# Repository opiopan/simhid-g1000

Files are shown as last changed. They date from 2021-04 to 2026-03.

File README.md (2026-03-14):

SimHID G1000
===
<p align="center">
description
</p>

SimHID G1000 is a input device that imitates Garmin G1000 glass cockpit system for controlling flight simulators.<br>
This device is designed to utilize a iPad as a display.
iPad, iPad Air or iPad Pro with a display from 10.2 inches to 11 inches can be applied to this device.<br>

SimHID G1000 not only has 41 push buttons and 14 axes rotary encoders like the actual Garmin G1000,
but also has a total 6 input switches on both side of left and right sides.
These additional switches allow you to switch one device between PFD and MFD for both purposes.<br>

SimHID G1000 behaves as a USB virtual serial device, and communicate with the host using proprietary protocol named SimHID protocol.
In order to recognize this protocol and to control switching between PFD and MFD, I made a Windows application called [fsmapper](https://opiopan.github.io/fsmapper).

## How to build
<p align="center">
description
</p>

The above image shows all parts that make up SimHID G1000.<br>
Most parts are 3D printed by FDM, but some parts are cut out and engraved from a 2mm thick acrylic plate using a laser cutter.
The model data for 3D printer and laser cutter are published at [Thingiverse](https://www.thingiverse.com/thing:4966493). Regarding these models, please refer [here](https://www.thingiverse.com/thing:4966493).

In this Github repository, PCB design and firmware source codes are hosted.<br>
Regarding PCB design related information include manufacturing, please refer README at [here](pcb/).<br>

Once all parts of SimHID G1000 are prepared, please assemble those according to [this procedure](docs/how-to-assemble.md).

**Note**: |
:----|
SimHID G1000 is entirely designed using [Fusion 360](https://www.autodesk.com/products/fusion-360/overview), including both mechanical and electrical components. If you want to modify the parts design, download [this Fusion 360 design file](https://raw.githubusercontent.com/wiki/opiopan/simhid-g1000/data/SimHID-G1000.f3d) and upload it to your Fusion 360 workspace.<br>Note that this file includes the 3D model of the PCB but does not contain the original netlist or artwork. The PCB design files are published separately [here](pcb), so upload them to Fusion 360 as well.

## Compatible iPad
board image

SimHID G1000 uses an iPad as display. 
I assume that an iPad behave as second display of Windows PC by using an application such as [Duet Display](https://duetdisplay.com),
and show PFD or MFD images rendered by a flight simulator.<br>
An iPad can be easily inserted from the top of the SimHID G1000 along the guide like as the right image.<br>
I've confirmed to fit with SimHID G1000 only in case of iPad Air gen 3, 
but I believe that all iPad families with display from 10.2 inches to 11 inches can be fit.

The iPad list compatible with SimHID G1000 is below (as of Mar. 2026).

|Class | Model
|:---:|---|
|iPad Pro | iPad Pro 10.5″<br>iPad Pro 11″ Gen 1<br>iPad Pro 11″ Gen 2<br>iPad Pro 11″ Gen 3<br>iPad Pro 11″ M4<br>iPad Pro 11″ M5
|iPad Air | iPad Air Gen 3<br>iPad Air Gen 4<br>iPad Air Gen 5<br>iPad Air 11″ M2<br>iPad Air 11″ M3<br>iPad Air 11″ M4
|iPad | iPad Gen 7<br>iPad Gen 8<br>iPad Gen 9<br>iPad Gen 10<br>iPad A16

## Compiling firmware
**Note**: |
:----|
The pre-built firmware can be downloaded from [here](https://github.com/opiopan/simhid-g1000/releases/latest/). If you haven’t modified the firmware code, using this version will be easier.

1. **Requirements**<br>
    Ensure that the [Arm GNU Toolchain](https://developer.arm.com/downloads/-/arm-gnu-toolchain-downloads) is installed and its bin folder is added to the `PATH` environment variable.
    Note that you need to install the toolchain for **AArch32 bare-metal** (`arm-none-eabi` variant).

    The Makefile for this firmware code is written with the assumption that it will be built in a Unix-like environment.
    If you are building on Windows, I strongly recommend using the Linux version of the Arm GNU Toolchain on WSL2.

2. **Downloading Source Codes**<br>
    ```shell
    $ git clone https://github.com/opiopan/simhid-g1000.git
    ```

3. **Compiling**
    ```shell
    $ cd simhid-g1000/firmware
    $ make all

## Programming Firmware
Once compiling as the above steps is done, following firmware binary files are made.
- ```firmware/build/simhid-g1000.elf``` : ELF format binary
- ```firmware/build/simhid-g1000.bin``` : raw binary

You can choose two way to program firmware to SimHID G1000.<br>
One is programming firmware via SWD by using debugger.  SimHID G1000 PCB exports a SWD I/F and you can access that from backside of this device.<br>
The other one is programming it via USB port in DFU mode. You can switch SimHID G1000 in DFU mode by inserting that to USB port with the button at right side pressed.

### Programming via Debugger
1. **Preparing Debugger**<br>
    Make sure that a debugger is connected with swd port (J6) and debugger controlling software which behave as GDB server such as OpenOCD is running.<br>
    Note that the J6 port does not have a power terminal, so you need to connect a USB port to supply power.

2. **Programming**<br>
    You can program a firmware by making ```flash``` target with ```DEBUGSERVER``` parameter.
    If debugger controlling software is running same PC, specify ```localhost``` for ```DEBUGSERVER``` parameter.

    ```shell
    $ make DEBUGSERVER=localhost flash
    ```
### Programming via USB
board image

1. **Install required software**<br>
    Make sure that software with programming function via DFU is installed.
    Following softwares are populor to use for this purpose.
    - [STM32CubeMXProgrammer](https://www.st.com/ja/development-tools/stm32cubeprog.html)
    - [dfu-util](http://dfu-util.sourceforge.net)

2. **Switching SimHID G1000 in DFU mode**<br>
    Hold down the button on the right side of SimHID G1000 and connect that with USB port on PC.

3. **Programming**<br>
    In case using dfu-util, you can program just by making ```dfuflash``` target.

    ```shell
    $ make dfuflash
    ```

    Othrewise, follow the instructions for the software you are using.

4. **Exsiting from DFU mode**<br>
    Pull out SimHID G1000 from USB port on PC, then re-connect that to USB port.

## SimHID protocol
SimHID G1000 communicate with PC using a proprietary protocol named SimHID protocol via USB virtual serial port.<br>
Initially, I was considering that SimHID G1000 behaves as USB HID device which can be handled by Windows standard USB gaming controller device driver.
However in the end, I decided to implement a proprietary protocol because of two issues.<br>

One issue is distinguishability of each operable elements.<br>
SimHID G1000 consists of 47 binary switches (push buttons) and 14 axes rotary encoders. when each rotary encoders is expressed 2 push buttons, such as for clockwise and for counter clockwise, SimHID G1000 is recognized as a device that consists of 75 buttons. In case handling this device by the standard USB HID gaming controller device driver, all buttons are distinguished only by their serial number. For example, the push button on top of the rotary encoder for setting the navigation frequency is #12, the switch representing the left of joystick for map panning is #62.<br>
This situation is very complicated for me when I setting up the mappings between SimHID G1000 operation and aircraft control. 
I wanted to assign each operable elements a descriptive name.

The other one issue was actually based on my misunderstanding regarding rotary encoder performance.<br>
I estimated that multiple clicks by rotary encoder's rotation can occur during the communication interval with host. It means that click event may be dropped if each click event is expressed as a simple push button.<br>
So, I tried to express each axes of rotary encoder as a analog axis of USB gaming controller device.
However, I soon realized that this plan doesn't work because Windows standard USB gaming controller device driver limits the number of analog axes to a maximum of 8
even though there is no limit in the USB HID specification.<br>
In practice, only one click event occurs during the communication interval with host in normal usage, and there is no problem even if each rotation click event is expressed as push button down and up event.<br>

In summary, I decided to design a new proprietary protocol and implement that due to the former issue.

SimHID protocol is designed to be both human readable and machine readable.
You can observe communication data between a SimHID device and a host by using general terminal emulation software with serial port connectivity such as screen command.<br>
All commands to the device, responses from the device, and asynchronous events occurred by device operation are expressed one line text ending with end of line mark. The end of line mark consists combination of CR and LF, in other words, ```0Dh``` and ```0Ah``` byte sequences or ```"\r\n"``` C string.

The following is a example of data sent from SimHID G1000 when the 100-feet unit altitude dial is rotated clockwise 3 clicks then rotated counterclockwise 2 clicks.
```
S EC4X 1
S EC4X 1
S EC4X 1
S EC4X -1
S EC4X -1
```

The following is a case of pushing the MENU button then releasing it.
```
S SW28 1
S SW28 0
```

The above examples shows the cases of notification from the device to the host.
On the other hand, SimHID protocol also assumes tha cases that the host send data to a device in order to change status of a element of a device, such as turning on a LED.<br>
This upstream communication will be done by same format data, "```S <element-name> <value> \r\n```".

Regarding the details of SimHID protocol specification, please refer [this document](docs/simhid-protocol.md).

## Companion software
As mentioned above, I made a windows application, [fsmapper](https://opiopan.github.io/fsmapper), to control a flight simulator by using SimHID G1000.

fsmapper not only allows you to use the SimHID G1000 as a Garmin G1000, but it can also recreate virtual instrument panels for various aircraft on a touch display, and integrate common control devices such as joysticks and throttles.
For examples of operating various aircraft using fsmapper and the SimHID G1000 combination, refer to the following video.

Showcase (https://youtu.be/rIp1M2r1_ko)

Integrating multiple instruments (https://youtu.be/tjl9g2BJMeQ)

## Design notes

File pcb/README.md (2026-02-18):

PCBs for SimHID G1000
===

> [!NOTE]
> SimHID G1000 was originally designed to use five [**ALPS EC11EBB24C03**](https://tech.alpsalpine.com/e/products/detail/EC11EBB24C03/) dual-shaft rotary encoders.
> This part was once discontinued (EOL) around 2022, but production and sales were resumed in 2025.<br/>
> As of now, [**EC11EBB24C03**](https://tech.alpsalpine.com/e/products/detail/EC11EBB24C03/) is marked as “**Not Recommended for New Designs**”, which means it is currently produced only to support existing designs, and its long-term availability is uncertain.
>
> For this reason, SimHID G1000 also supports [**BOURNS PEC11D-4120F-S0015**](https://www.bourns.com/products/encoders/contacting-encoders/product/PEC11D) as an alternative.
> This encoder is electrically and functionally compatible with the ALPS part, with the main difference being the shaft geometry.<br/>
> If you choose to use [**PEC11D-4120F-S0015**](https://www.bourns.com/products/encoders/contacting-encoders/product/PEC11D), please use [the alternative dual-shaft knob design provided here](https://www.thingiverse.com/thing:5804384).

<p align="center">
description
</p>

The operable parts of SimHID G1000, the rotary encoders and push buttons, are distributed and mounted on three PCBs.<br>
The right board is the main board. The MCU [STM32F411CCU](https://www.st.com/en/microcontrollers-microprocessors/stm32f411cc.html) which is installed on the right board exports USB full speed PHY and communicate with PC via it.
That MCU also observes all operable components state via 16bits SPI I/O expanders, [MCP23S18-E/MJ](https://www.microchip.com/en-us/product/MCP23S18), on each PCB.<br>
Each PCB is connected with each other via 8-wire interconnect that consists 2 for power supply, 3 for SPI, and 3 for chip select.

I designed two variants of the PCB using [Autodesk Eagle](https://www.autodesk.com/products/eagle/overview) and same functions embedded in [Autodesk Fusion 360](https://www.autodesk.com/products/fusion-360/overview).
In the first variant, designed in March 2021, I used the [MCP23S18-E/MJ](https://www.microchip.com/en-us/product/MCP23S18) (QFN24) as the I/O expander. However, this component never made it to JLCPCB’s parts library.
At the time, with the chip shortage in full swing, other components were also out of stock, so I didn’t pay much attention to it. 
Now that the supply-demand situation for chips has improved, I decided to design a variant that uses components easier to manufacture with JLCPCB’s PCBA service. 
In the second variant, designed in September 2023, I replaced the MCP23S18-E/MJ with the [MCP23S17-E/ML](https://www.microchip.com/en-us/product/MCP23S17) (QFN28) and reduced the components mounted on the back of the PCB to only the Micro USB connector.

> [!NOTE]
> In late 2024, two additional PCB variants were designed primarily to improve the visual appearance of the device.  
> In the original design, the Micro USB connector is located on the right side of the PCB. Since the device must remain connected to a PC while in use, the USB cable is always visible, which the author personally found distracting.   
>
> The two new variants relocate the USB connector to the rear side of the PCB, allowing the cable to be routed out of sight.
> **Variant 3** uses a Micro USB connector, while **Variant 4** supports USB Type-C.
> 
> 3D-printable parts compatible with these rear-connector variants are also available for [download here](https://www.thingiverse.com/thing:7290593).

The design files of each PCB and the files required for manufacturing such as gerber files can be found below.

PCB Variant       | Eagle design files | Gerber files |BOM file| CPL file|Remarks
------------------|:-:|:-:|:-:|:-:|---
Variant 1|[handsoldering/individuals](handsoldering/individuals)|[PCB.zip](https://raw.githubusercontent.com/wiki/opiopan/simhid-g1000/data/allcomponents/PCB.zip)|[BOM.csv](https://raw.githubusercontent.com/wiki/opiopan/simhid-g1000/data/allcomponents/BOM.csv)|[CPL.csv](https://raw.githubusercontent.com/wiki/opiopan/simhid-g1000/data/allcomponents/CPL.csv)| Not recommended due to parts availability
Variant 2|[reflow/individuals](reflow/individuals)|[PCB_var2.zip](https://raw.githubusercontent.com/wiki/opiopan/simhid-g1000/data/allcomponents2/PCB_var2.zip)|[BOM_var2.csv](https://raw.githubusercontent.com/wiki/opiopan/simhid-g1000/data/allcomponents2/BOM_var2.csv)|[CPL_var2.csv](https://raw.githubusercontent.com/wiki/opiopan/simhid-g1000/data/allcomponents2/CPL_var2.csv)| Micro USB (right side)
Variant 3|[reflow2/individuals](reflow2/individuals)|[PCB_var3.zip](https://raw.githubusercontent.com/wiki/opiopan/simhid-g1000/data/allcomponents3/PCB_var3.zip)|[BOM_var3.csv](https://raw.githubusercontent.com/wiki/opiopan/simhid-g1000/data/allcomponents3/BOM_var3.csv)|[CPL_var3.csv](https://raw.githubusercontent.com/wiki/opiopan/simhid-g1000/data/allcomponents3/CPL_var3.csv)| Micro USB (rear)<br/>Requires the [different 3D-printed parts](https://www.thingiverse.com/thing:7290593)
Variant 4|[reflow3/individuals](reflow3/individuals)|[PCB_var4.zip](https://raw.githubusercontent.com/wiki/opiopan/simhid-g1000/data/allcomponents4/PCB_var4.zip)|[BOM_var4.csv](https://raw.githubusercontent.com/wiki/opiopan/simhid-g1000/data/allcomponents4/BOM_var4.csv)|[CPL_var4.csv](https://raw.githubusercontent.com/wiki/opiopan/simhid-g1000/data/allcomponents4/CPL_var4.csv)| USB Type-C (rear)<br/>Requires the [different 3D-printed parts](https://www.thingiverse.com/thing:7290593)

The PCB manufacturing files provided in the table — including the Gerber archive, BOM file, and CPL file — conform to [JLCPCB](https://jlcpcb.com/)’s rules and requirements.   
You can submit these files directly to the [JLCPCB PCB Assembly Service](https://cart.jlcpcb.com/quote) without modification.

When using the above file to manufacture the PCB at JLCPCB, specify the following parameters during production.

Parameter | Specification
----------|--------------
Different Design|3
PCB Thickness| 1.0 mm
Tooling holes| Added by Customer
PCBA Type /<br>Assembly Side|My recommendation is ***'Economic'*** for the ***'PCBA Type'*** and ***'Top Side'*** for the ***'Assembly Side'***.<br><br>When assembling components on both sides of the board, you must select ***'Standard'*** for the ***'PCBA Type'***. This results in a significant cost increase. For example, if you manufacture two units of Variant 2, selecting ***'Economic'*** and ***'Top Side'*** costs $188.07, whereas selecting ***'Standard'*** and ***'Both Side'*** increases the price to $270.25. That’s quite a large amount to pay for soldering just two Micro USB connectors, each costing only $0.34, isn’t it?<br><br>If you use the PCBA service to assemble only the top side, you’ll need to manually solder following parts on the bottom side yourself;<br/> - **Variant 1**: [MCP1703AT-3302E/CB](https://www.digikey.com/en/products/detail/microchip-technology/MCP1703AT-3302E-CB/3131472) and [ZX62-B-5PA(33)](https://www.hirose.com/en/product/p/CL0242-0033-8-33)<br/> - **Variant 2**: [ZX62-B-5PA(33)](https://www.hirose.com/en/product/p/CL0242-0033-8-33)<br/> - **Variant 3**: [1051330031](https://www.molex.com/en-us/products/part-detail/1051330031)<br/> - **Variant 4**: [USB4145](https://gct.co/connector/usb4145)

<p align="center">
PCBA service
</p>

## Schematic Diagram

<p align="center">
PCB schema
</p>
<p align="center">
PCB schema
</p>
<p align="center">
PCB schema
</p>

## BOM List
Components | Value / Product Number | Remarks
-----------|------------------------|------------------------------
U1, U2, U3, U5 | MCP23S18-E/MJ or MCP23S17-E/ML | 16bits SPI I/O expander
U4         | STM32F411CCU           |
U6         | MCP1703AT-3302E/CB     | SOT-23 LDO
J1         | **Var1/2**: Hirose ZX62-B-5PA(33)<br/>**Var3**: Molex 1051330031<br/>**Var4**: GCT USB4145  | Micro USB receptacle connector (Variant 1/2/3)<br/>USB Type-C receptacle connector (Variant 4)
J6         | MOLEX 53047-0410       | **OPTIONAL for debugging**<br>Firmware downloading can be proceeded by using DFU mode instead debugger
X1         | 16MHz Crystal (3225)   | load capacitance: 10pF
C1, C2, C3, C9, C10, C11, C12, C13, C14, C15, C17, C19, C20  | 0.1uF (0402)             |
C4, C5, C8 | 1uF (0402)           |
C6, C7     | 22pF (0402)            | need to change value if X1's load capacitance is not 10pF
C16, C18   | 4.7uF (0402)           |
R1, R2, R11, R12, R13, R14, R15, R16, R17,<br> R18, R19, R20, R21, R22, R23, R24, R25, R26,<br> R27, R28, R29, R30, R31, R32, R33, R34, R35,<br> R36, R37, R38, R39, R40, R41, R42, R43, R44,<br> R45, R46, R47, R48, R49, R50, R51, R52, R53, R54, R55, R56, R57, R58, R59| 10k ohm (0402)         |
R3, R4, R5, R6, R7, R8, R9, R10     | 10k ohm x 4 (0603 x 4) | 
R60, R61| 5.1K ohm (0402)| Applicable to Variant 4 only
SW1, SW27  | SLLB510100           |
SW2, SW3, SW4, SW5, SW6, SW7, SW8, <br>SW9, SW10, SW11, SW12, SW13, SW14,<br> SW15, SW16, SW17, SW18, SW19, SW20,<br> SW21, SW22, SW23, SW24, SW25, SW26,<br> SW28, SW29, SW30, SW31, SW32, SW33, SW34 | 4.5mm x 4.5mm tact switch | 4.3mm height
EC1, EC3, EC5 | EC12D1524403 | 1 axis rotary encoder with push button
EC2, EC4, EC6, EC7, EC9 | EC11EBB24C03 or PEC11D-4120F-S0015 | 2 axes rotary encoder with push button
EC8 | RKJXT1F42001 | 4 directional joystick with 1 axis rotary encoder and push button

## Supplement
### PCB interconnect
Each PCB are connected to adjacent PCB via the 8 pads junction for interconnect, that are J2, J3, J4 and J5.<br>
It is recommended to solder the interconnect with the PCBs fixed to the front housing of SimHID G1000 in order to properly adjust the length of the wires connecting between PCBs as below.

<p align="center">
description
</p>

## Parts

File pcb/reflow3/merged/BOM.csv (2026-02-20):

Comment | Designator | Footprint | LCSC Part # (optional)
100nF | C1,C2,C3,C9,C10,C11,C12,C13,C14,C15,C17,C19,C20 | C0402 | C1525
1uF | C4,C5,C8 | C0402 | C52923
22pF | C6,C7 | C0402 | C1555
4.7uF | C16,C18 | C0402 | C23733
10KOHMS | R1,R2,R11,R12,R13,R14,R15,R16,R17,R18,R19,R20,R21,R22,R23,R24,R25,R26,R27,R28,R29,R30,R31,R32,R33,R34,R35,R36,R37,R38,R39,R40,R41,R42,R43,R44,R45,R46,R47,R48,R49,R50,R51,R52,R53,R54,R55,R56,R57,R58,R59 | R0402 | C25744
10KOHMSx4 | R3,R4,R5,R6,R7,R8,R9,R10 | RES-ARRAY-SMD_0603-8P-L3.2-W1.6-BL | C29718
TS-1109S-B-B | SW2,SW3,SW4,SW5,SW6,SW7,SW8,SW9,SW10,SW11,SW12,SW13,SW14,SW15,SW16,SW17,SW18,SW19,SW20,SW21,SW22,SW23,SW24,SW25,SW26,SW28,SW29,SW30,SW31,SW32,SW33,SW34 | SW-SMD_4P-L4.5-W4.5-P3.00-LS7.0 | C480315
16MHZ | X1 | OSC-SMD_4P-L3.2-W2.5-BL | C13738
MCP23S17T-E/ML | U1,U2,U3,U5 | QFN-28_L6.0-W6.0-P0.65-BL-EP3.7 | C629442
STM32F411CCU6TR | U4 | QFN-48_L7.0-W7.0-P0.50-BL-EP5.1 | C190642
MCP1703AT-3302E/CB | U6 | SOT-23-3_L2.9-W1.3-P1.90-LS2.4-BR | C144183
SLLB510100 | SW1,SW27 | SW-SMD_SLLB510100 | C125039
EC12D1524403 | EC1,EC3,EC5 | SW-TH_EC12D1524403 | C112349
EC11EBB24C03 | EC2,EC4,EC6,EC7,EC9 | SW-TH_EC11EBB24C03 | C470790
RKJXT1F42001 | EC8 | SW-TH_RKJXT1F42001 | C160841
USB4145-03-0070-C | J5 | USB-C-SMD_USB4145-03-0070-C | C5815189
5.1KOHMS | R60,R61 | R0402 | C25905

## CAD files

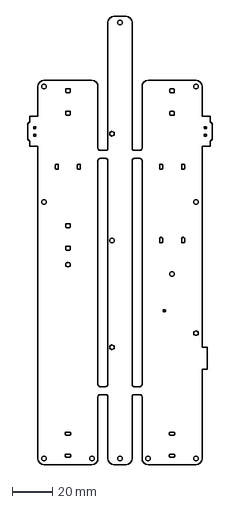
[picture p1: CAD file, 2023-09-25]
pcb/handsoldering/merged/outline.dxf
92.1 x 224.0 mm

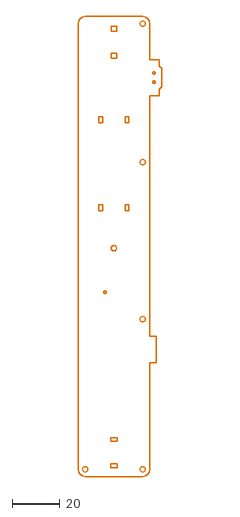
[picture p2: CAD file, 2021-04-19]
pcb/reflow/individuals/simhid-g1000_right.dxf
35.0 x 192.0

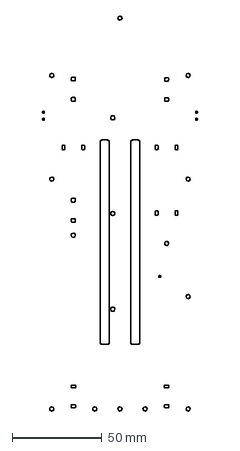
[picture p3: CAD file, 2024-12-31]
pcb/reflow3/merged/holes.dxf
86.5 x 220.3 mm

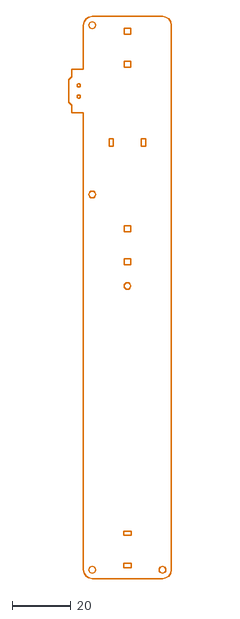
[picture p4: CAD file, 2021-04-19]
pcb/reflow/individuals/simhid-g1000_left.dxf
35.0 x 192.0

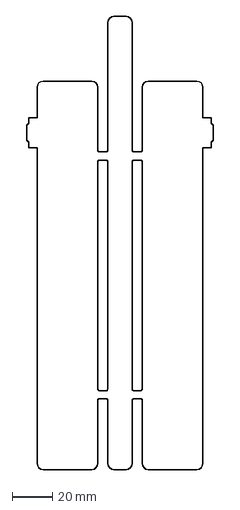
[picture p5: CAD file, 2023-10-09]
pcb/reflow3/merged/outline.dxf
92.1 x 224.0 mm

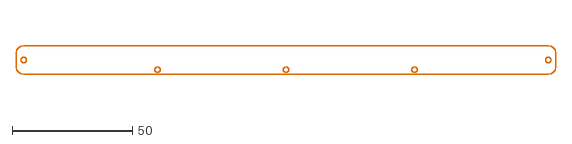
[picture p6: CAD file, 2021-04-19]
pcb/reflow/individuals/simhid-g1000_bottom.dxf
224.0 x 12.0

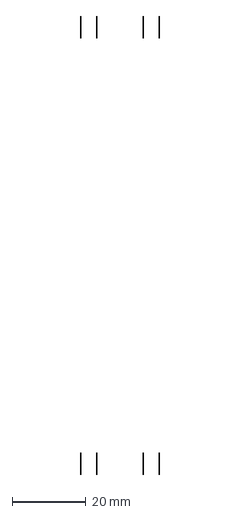
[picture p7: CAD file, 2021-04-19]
pcb/reflow3/merged/mousebites.dxf
21.3 x 124.0 mm

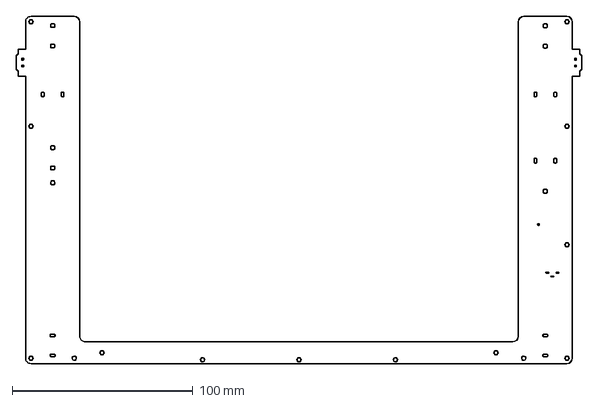
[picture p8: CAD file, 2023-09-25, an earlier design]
pcb/uniboard2/merged/outline.dxf
312.6 x 192.0 mm

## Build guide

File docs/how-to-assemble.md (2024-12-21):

How to assemble SimHID G1000
===
Refer to followings and prepare all parts that make up SimHID G1000 in advance.

- [3D printed parts and laser cut acrylic plate](https://www.thingiverse.com/thing:4966493)
- [PCB](../pcb)

## 1. Assemble front housing
The front housing is divided into 6 parts. Fasten all parts with **M2 4mm pan head screws**.<br>
The points to fixed by screws are below.

<p align="center">
description
</p>

## 2. Adhere acrylic panel parts
Adhere all acrylic panel parts on front housing or button base parts as following image.
The parts printed from "```jig.stl```" should help you to align parts when you adhere the parts top of button and button base.<br>
I used double-sided tape for the front housing and cyanoacrylate adhesive for the buttons.

<p align="center">
description
</p>

## 3. Place the buttons
Place the all buttons in the correct position and orientation from the back side of the front housing.

<p align="center">
description
</p>

## 4. Attach PCBs to the front housing
Fasten three PCBs to the front housing with two types of M2 screws, one type is **M2 4mm pan head screw**, the other one type is **M2 hex male-female spacer with 4mm male part and 8mm spacer part**.<br>
The following image shows places for each screws that yellow for pan head screws and red for spacers.

<p align="center">
description
</p>

## 5. Attach the back housing
Fasten the back housing parts with 11 **M2 4mm pan head screws** at the yellow points as below.

<p align="center">
description
</p>

## 6. Insert the knobs
Insert the all knobs to each axis of the rotary encoders.

<p align="center">
description
</p>

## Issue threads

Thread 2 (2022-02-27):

4.3mm tact switch

farcouet, 2022-02-27:
Hello,
Wow awsome work!
Unfortunately some parts are currently out of stock at both digikey and mouser but I will order everything and wait.

My only issue is I am unable to find any tact switches that are 4.5mmx4.5mm with a 4.3mm height. I only see 3.8mm and 5mm.
Do you have any part number? Is it really 4.3mm that is required?
Thanks!
Fred

farcouet, 2022-02-27:
Ok I have not seen that it was possible to have those ordered and soldered by JLCPCB. So I will have that done and save a lot of time ;-) thanks!

Closed 2022-02-27.

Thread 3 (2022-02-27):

Can STM32F411CEU6 be used instead of STM32F411CCU6TR

farcouet, 2022-02-27:
Hello
As the STM32F411CCU6TR is backorder everywhere I was trying to find a replacement. None are stock but there are dev board on ebay with a STM32F411CEU6 and I was thinking of ordering one and take it from that board.
The only difference that I am seeing is the flash that is double on the STM32F411CEU6. Can it be used? I am not familiar with those STMicro mcu.
Thanks,
Fred

farcouet, 2022-02-28:
Hello!
Yes kind of. Situation was not that bad a year ago with Mouser and Digikey even if we started to hear about it. But since 9 months now it hits pretty bad!
So perfect I have ordered the little dev board on ebay and will salvage the MCU from it! I have sent the PCB to be made by JLCPCB and kind of nice to have them solder the small 0402 instead of spending time on this! I was lucky as all other parts except the MCU and the USB connectors were available. I will salvage also the USB from the dev board!
I got the last port expander they had.
Still printing the parts and need to find a place for the laser cut & engraving.
Hopefully will complete this in few weeks (time to get also the board).
Thanks!
Fred

sunilsinsinwar, 2024-02-23:
Hello
    usb device not recognise error.Device Descriptor Request Failed.
any solution.
may you share the hex file please

Closed 2024-12-31.

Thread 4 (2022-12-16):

Input off-by-one?

GregoryHlavac, 2022-12-16:
On left-side board to start the topmost tactile button is labeled SW2 but comes through the FSmapper application as SW1, is this an actual problem or just a misconfiguration on display somewhere?

opiopan, 2022-12-16:
That is right behavior.
I renamed the two lever switches labeled SW1 and SW27 on PCB to AUX1 and AUX2 when I wrote firmaware codes.
So, tactile switch numbers are rearranged 1 to 32.

GregoryHlavac, 2022-12-17:
Ah, thanks.

Closed 2022-12-17.

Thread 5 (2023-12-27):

Hello I just ordered pcb at jlc and got a message

Puruenhanuel, 2023-12-27:
Pcb design that you uploaded has 3designs do I need to print them all or is there any specific design do I need to use?

I am noob on this and I just want to make it …

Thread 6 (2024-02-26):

Simhid Protocol

LucasHL2104, 2024-02-26:
Hi,
I have a problem with fsmapper, my g1000 is actually recognize as "usb serial device (com5)"
it show me this error :
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

Closed 2024-02-29.

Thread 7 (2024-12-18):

Wrong dual encoder part number?

Drachenkaetzchen, 2024-12-18:
The documentation refers to `PEC11D-4120F-20015` which seems not to be a valid part number. `PEC11D-4120F-S0015` seems to be the proper one, is that correct?

opiopan, 2024-12-20:
Thank you for reporting the mistake in the document. As you correctly pointed out, `PEC11D-4120F-S0015` is correct.
I will fix this mistake.

Drachenkaetzchen, 2024-12-20:
Thank you for the fix! Looking forward building this project!

Closed 2024-12-20.

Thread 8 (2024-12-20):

Compiling Firmware

mAkhenaton, 2024-12-20:
Hello,
Thank you very much for the project, and all the detailed information,
i have a little issue with compiling the firmware, after 5 hours of testing and research i was unable to compile the firmware using the Make file, i think i installed everything like it should but i am getting 1 error , the compilation is creating a build folder , with an empty version file.
I am not a code expert , i really tried , but i seem to be missing something. i can really use some help or the files already compiled , it will be great .(unless a step by step explanation is possible , it would be interesting to see what i am doing wrong ).
Thank you very much,

i am using windows 10
i tested:
 -GNU arm gnu 14.2
-winget install ezwinports.make in win cmd
- cygwin with the correspondant packages for make .....

opiopan, 2024-12-21:
I have published pre-built firmware binaries [here](https://github.com/opiopan/simhid-g1000/releases/latest/), so would you like to try this?

Actually, I developed this gadget entirely on a Mac, and the Makefile for building the firmware was designed with Unix-like environments in mind. Because of this, building it on a Mac or Linux should work without any issues. However, attempting to build it in a native Windows environment might be challenging just to gather the necessary tools.

I’m not familiar with the numerous Posix-compatible environments available for Windows, so I can’t provide precise advice on how to proceed. That said, these days, using WSL2 is probably the easiest way to get things working without much hassle. Earlier, I tried building the firmware for simhid-g1000 on WSL2 (Ubuntu) with nothing more than the Arm GNU Toolchain installed, and everything worked perfectly without any issues.

In any case, not including this kind of information in the README might have made things a bit unclear. I’ll update the README to address this. Thank you for your report.

mAkhenaton, 2024-12-21:
Thank you for your fast response & sharing the files,
i really appreciated , i will be testing everything this evening, and retrying with wsl2 & will try flashing with the files you shared too.
Anyways i will Keep you posted & great job man,
best regards

opiopan, 2025-01-10:
> I had a similar issue yesterday, the script tools/version needs the executable flag (chmod +x tools/version). Unfortunately you did not post the full error output, so I can only guess if that helps you.

Interesting. That phenomenon might indeed be occurring.
If so, it looks like one of the typical issues seen when mixing different POSIX compatibility layers.
For example, if the repository is cloned using a git command that is not based on Cygwin, such as Git for Windows, the emulation of POSIX file permissions using Windows ACLs (as implemented by Cygwin) will not occur. As a result, all files would appear as mode 666 from within the Cygwin environment.
When using Cygwin’s make, it is preferable to also use the Cygwin version of git.

In any case, building a POSIX-compatible environment on Windows is quite complex.

Drachenkaetzchen, 2025-01-10:
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

This happened to me on Arch Linux, not on Windows.

opiopan, 2025-01-10:
Your case occurred on Linux, I see. In that case, could it be that your git configuration is set to not track changes in file mode?
How about checking the value of `core.filemode` with `git config -l`?

Drachenkaetzchen, 2025-01-10:
> Your case occurred on Linux, I see. In that case, could it be that your git configuration is set to not track changes in file mode? How about checking the value of `core.filemode` with `git config -l`?

```
[dragonkitty@zerodawn ~]$ git config -l
[dragonkitty@zerodawn ~]$ git config get core.filemode
[dragonkitty@zerodawn ~]$
```

It is not set, git config is all set to defaults. I don't think this is something users should fix - the script to create the version should be called only if it is executable, and if it is not, either issue an error or use an interpreter to execute it.

opiopan, 2025-01-10:
I think this is an issue on the user side. Tracking file execute permissions is a standard feature of git.
If there are any articles or resources suggesting that script files should not have execute permissions, please let me know.

opiopan, 2025-01-11:
I finally understand the point you were trying to make. Even if there is an issue with the file mode of tools/version, the make process continues without interruption, making it difficult for users to identify the problem.
I’ve modified the Makefile, could you check if it resolves the issue?

Closed 2025-01-11.

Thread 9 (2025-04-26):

USB connection not being detected

scott-ish, 2025-04-26:
I ordered variant 2 from JLPCB which has arrived. I've soldiered on a micro usb connector. When I plugin a usb to a PC I get no connection and no serial ports in device manager.
I've tested that the board has 5v and is generating 3.3v. The 2 usb data lines are connected to the STM32 as I checked with a meter from the PC end of the USB cable to ground, 5v, data 1/2.
I bought a ST link and it detects the CPU and I can upload the firmware without issue. But I still get no usb connection.
I had 2 boards made up and I've tested on the other board and get the same results. Tried different wires, different PCs and the 2 boards.

Anyone have any ideas where am I going wrong here?

opiopan, 2025-04-27:
As far as I know, if you can access the MCU through the debugger but it is not recognized as a DFU mode USB device, it is often due to poor soldering of the micro USB connector.

If there is no problem with the soldering, how about trying to see if it can be recognized in DFU mode by following steps?
https://github.com/opiopan/simhid-g1000?tab=readme-ov-file#programming-via-usb

scott-ish, 2025-04-28:
So got this resolved.
I had left the ST Link connected to the board and that seemed to be causing some ground or reset issue. Once I disconnected that I got a com connection and data coming through.

Thanks for the help and for sharing a brilliant project.

Closed 2025-04-28.

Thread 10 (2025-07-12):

BIT for certain IO expanders failed

opiopan, 2025-07-12:
This issue will be used to track the BIT failures reported for certain IO expanders reported in [the other issue](https://github.com/opiopan/fsmapper/issues/10).

In the environment of the reporter, [scott-ish](https://github.com/scott-ish), one of the two SimHID G1000 units consistently fails BIT, while the other occasionally passes with a low probability.
Notably, even when the BIT fails, the operation events from the devices managed by the corresponding IO expander are generated without issue.

One possible cause is a timing issue during the IO expander’s power-on sequence.
Extending the sleep duration during firmware startup might resolve the issue.

opiopan, 2025-07-12:
Assuming that the issue may be due to POR timing variations caused by PCB differences, the firmware has been modified to retry BIT once, 300 ms after the initial failure (cdf07bc).

If you’re experiencing this issue, please either build commit cdf07bc or download the firmware binary linked below, and report whether the problem is resolved in your environment.
[simhid-g1000-firmware_v1.2.14.zip](https://github.com/user-attachments/files/21199867/simhid-g1000-firmware_v1.2.14.zip)

If this fix proves to resolve the issue, It will be released as v1.3 firmware.

opiopan, 2025-07-21:
Thank you for testing v1.2.14. I’m glad to hear that the BIT retry appears to be effective.
I’ll proceed to officially release this firmware version.

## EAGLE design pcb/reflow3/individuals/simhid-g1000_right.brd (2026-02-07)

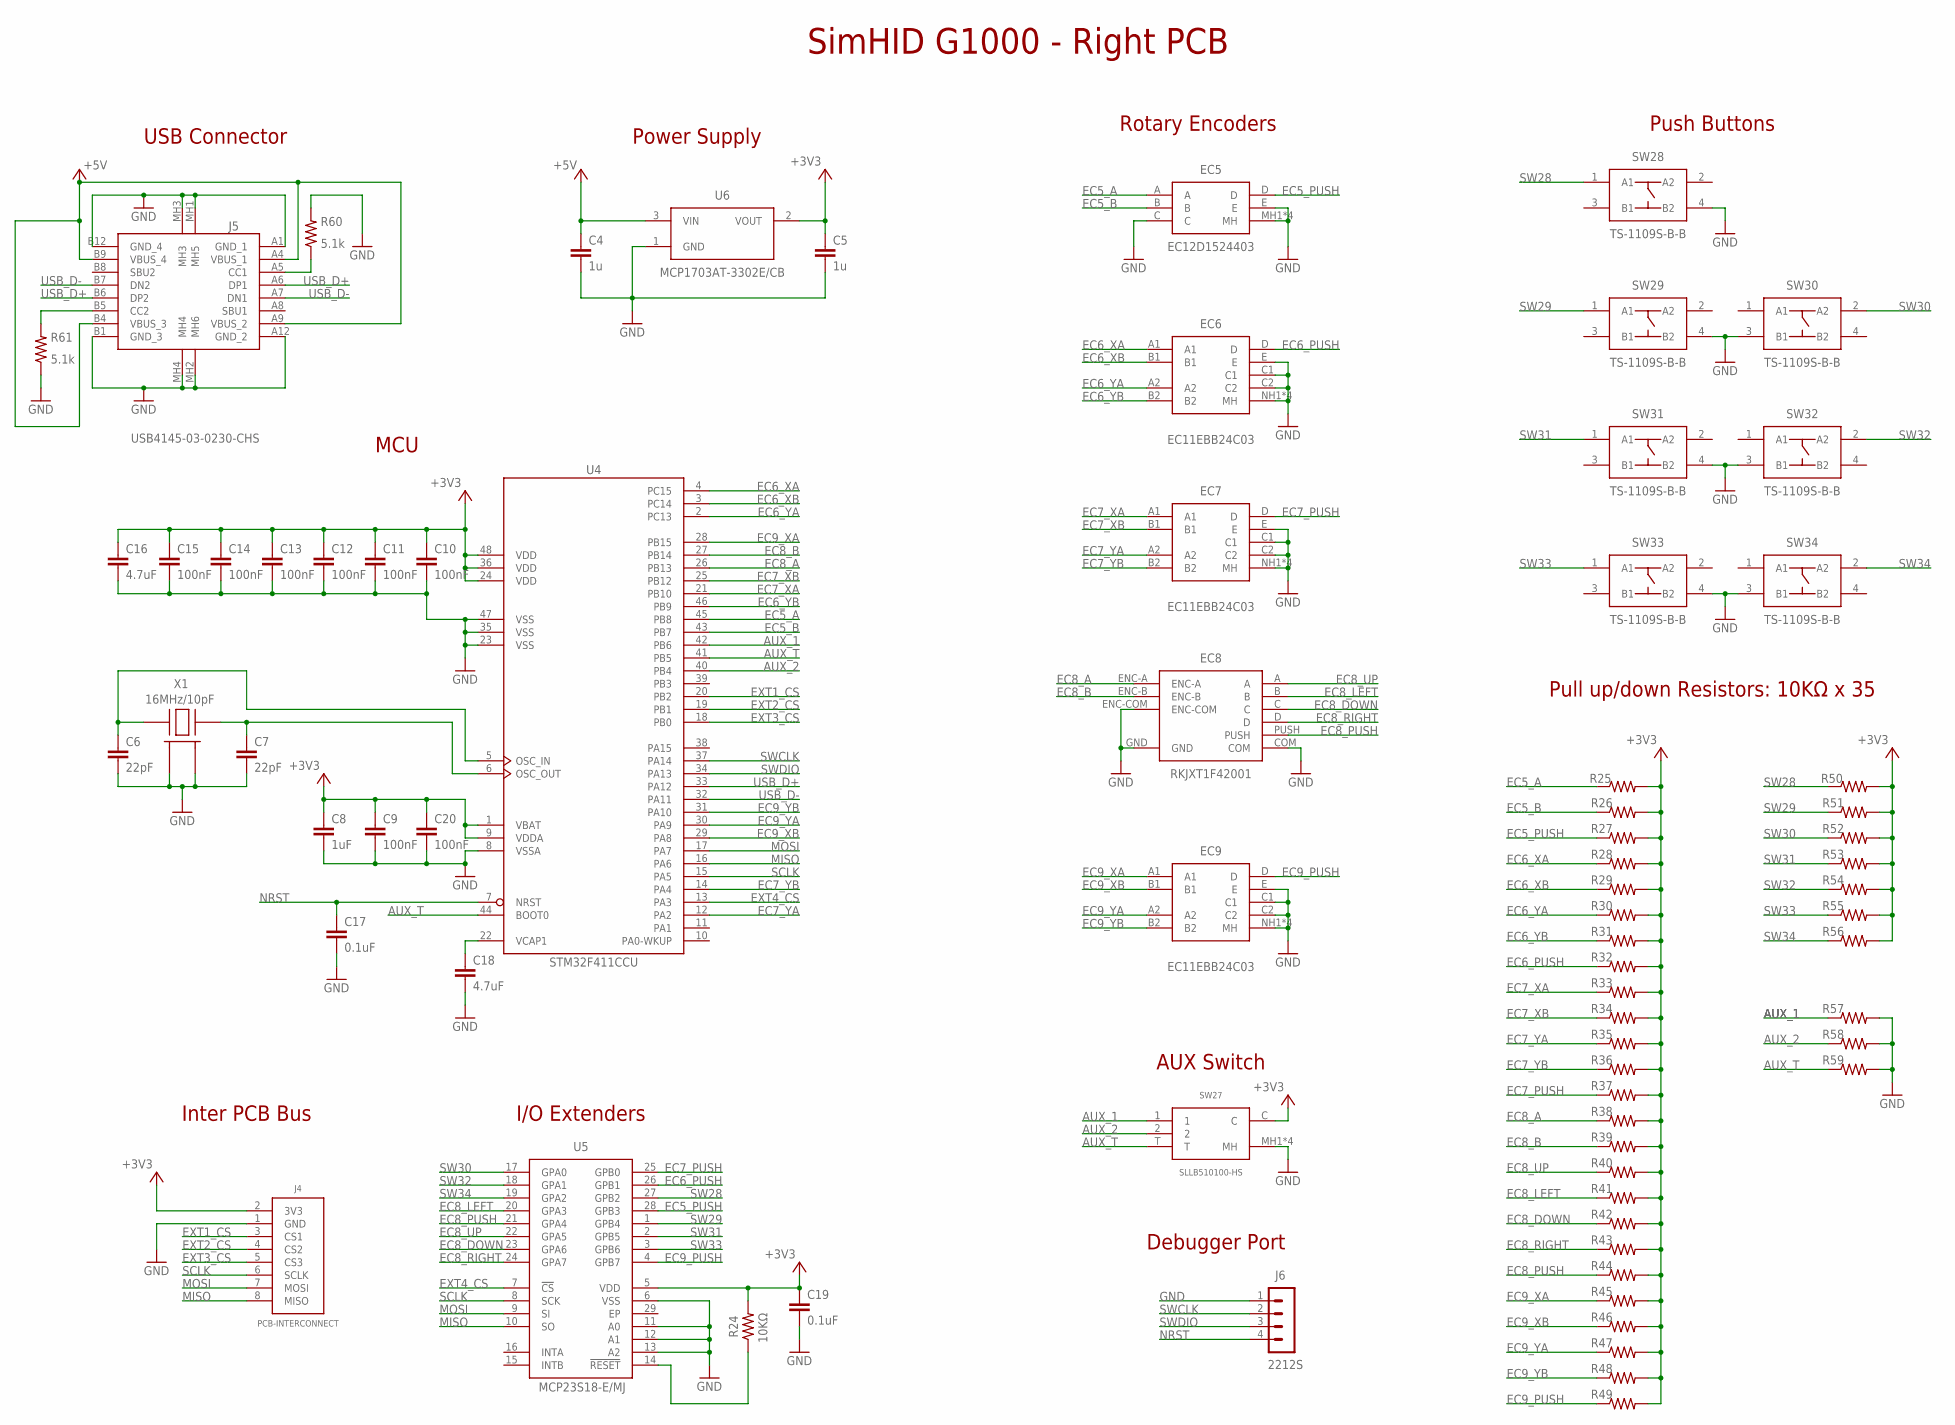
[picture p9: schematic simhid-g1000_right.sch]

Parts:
C4, C5: 1u; RCL_C0402_HS
C6, C7: 22pF; RCL_C0402_HS
C8: 1uF; RCL_C0402_HS
C9, C10, C11, C12, C13, C14, C15, C20: 100nF; RCL_C0402_HS
C16, C18: 4.7uF; RCL_C0402_HS
C17, C19: 0.1uF; RCL_C0402_HS
EC5: EC12D1524403
EC6, EC7, EC9: EC11EBB24C03
EC8: RKJXT1F42001
J4: PCB-INTERCONNECT
J5: USB4145-03-0230-CHS; USB4145030230C-HS
J6: 2212S; 53047-0410
R24: 10KΩ; RCL_R0402_HS
R25, R26, R27, R28, R29, R30, R31, R32, R33, R34, R35, R36, R37, R38, R39, R40, R41, R42, R43, R44, R45, R46, R47, R48, R49, R50, R51, R52, R53, R54, R55, R56, R57, R58, R59: RCL_R-US_R0402-HS; RCL_R0402_HS
R60, R61: 5.1k; RCL_R0402_HS
SW27: SLLB510100-HS
SW28, SW29, SW30, SW31, SW32, SW33, SW34: TS-1109S-B-B
U4: STM32F411CCU; UFQFPN48
U5: MCP23S18-E/MJ; QFN65P600X600X100-29N
U6: MCP1703AT-3302E/CB; SOT23
X1: 16MHz/10pF; CRYSTAL3225-HS

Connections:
+3V3: C5.1, C8.1, C9.1, C10.1, C11.1, C12.1, C13.1, C14.1, C15.1, C16.1, C19.1, C20.1, J4.2 (3V3), R24.2, R25.2, R26.2, R27.2, R28.2, R29.2, R30.2, R31.2, R32.2, R33.2, R34.2, R35.2, R36.2, R37.2, R38.2, R39.2, R40.2, R41.2, R42.2, R43.2, R44.2, R45.2, R46.2, R47.2, R48.2, R49.2, R50.2, R51.2, R52.2, R53.2, R54.2, R55.2, R56.2, SW27.C, U4.1 (VBAT), U4.9 (VDDA), U4.24 (VDD), U4.36 (VDD), U4.48 (VDD), U5.5 (VDD), U6.2 (VOUT)
+5V: C4.1, J5.A4 (VBUS_1), J5.A9 (VBUS_2), J5.B4 (VBUS_3), J5.B9 (VBUS_4), U6.3 (VIN)
AUX_1: R57.1, SW27.1, U4.42 (PB6)
AUX_2: R58.1, SW27.2, U4.40 (PB4)
AUX_T: R59.1, SW27.T, U4.41 (PB5), U4.44 (BOOT0)
EC5_A: EC5.A, R25.1, U4.45 (PB8)
EC5_B: EC5.B, R26.1, U4.43 (PB7)
EC5_PUSH: EC5.D, R27.1, U5.28 (GPB3)
EC6_PUSH: EC6.D, R32.1, U5.26 (GPB1)
EC6_XA: EC6.A1, R28.1, U4.4 (PC15)
EC6_XB: EC6.B1, R29.1, U4.3 (PC14)
EC6_YA: EC6.A2, R30.1, U4.2 (PC13)
EC6_YB: EC6.B2, R31.1, U4.46 (PB9)
EC7_PUSH: EC7.D, R37.1, U5.25 (GPB0)
EC7_XA: EC7.A1, R33.1, U4.21 (PB10)
EC7_XB: EC7.B1, R34.1, U4.25 (PB12)
EC7_YA: EC7.A2, R35.1, U4.12 (PA2)
EC7_YB: EC7.B2, R36.1, U4.14 (PA4)
EC8_A: EC8.ENC-A, R38.1, U4.26 (PB13)
EC8_B: EC8.ENC-B, R39.1, U4.27 (PB14)
EC8_DOWN: EC8.C, R42.1, U5.23 (GPA6)
EC8_LEFT: EC8.B, R41.1, U5.20 (GPA3)
EC8_PUSH: EC8.PUSH, R44.1, U5.21 (GPA4)
EC8_RIGHT: EC8.D, R43.1, U5.24 (GPA7)
EC8_UP: EC8.A, R40.1, U5.22 (GPA5)
EC9_PUSH: EC9.D, R49.1, U5.4 (GPB7)
EC9_XA: EC9.A1, R45.1, U4.28 (PB15)
EC9_XB: EC9.B1, R46.1, U4.29 (PA8)
EC9_YA: EC9.A2, R47.1, U4.30 (PA9)
EC9_YB: EC9.B2, R48.1, U4.31 (PA10)
EXT1_CS: J4.3 (CS1), U4.20 (PB2)
EXT2_CS: J4.4 (CS2), U4.19 (PB1)
EXT3_CS: J4.5 (CS3), U4.18 (PB0)
EXT4_CS: U4.13 (PA3), U5.7 (!CS)
GND: C4.2, C5.2, C6.2, C7.2, C8.2, C9.2, C10.2, C11.2, C12.2, C13.2, C14.2, C15.2, C16.2, C17.2, C18.2, C19.2, C20.2, EC5.C, EC5.E, EC5.MH1 (MH), EC5.MH2 (MH), EC5.MH3 (MH), EC5.MH4 (MH), EC6.C1, EC6.C2, EC6.E, EC6.NH1 (MH), EC6.NH2 (MH), EC6.NH3 (MH), EC6.NH4 (MH), EC7.C1, EC7.C2, EC7.E, EC7.NH1 (MH), EC7.NH2 (MH), EC7.NH3 (MH), EC7.NH4 (MH), EC8.COM, EC8.ENC-COM, EC8.GND, EC9.C1, EC9.C2, EC9.E, EC9.NH1 (MH), EC9.NH2 (MH), EC9.NH3 (MH), EC9.NH4 (MH), J4.1 (GND), J5.A1 (GND_1), J5.A12 (GND_2), J5.B1 (GND_3), J5.B12 (GND_4), J5.MH1 (MH5), J5.MH2 (MH6), J5.MH3, J5.MH4, J6.1, R57.2, R58.2, R59.2, R60.2, R61.1, SW27.MH1 (MH), SW27.MH2 (MH), SW27.MH3 (MH), SW27.MH4 (MH), SW28.4 (B2), SW29.4 (B2), SW30.3 (B1), SW31.4 (B2), SW32.3 (B1), SW33.4 (B2), SW34.3 (B1), U4.8 (VSSA), U4.23 (VSS), U4.35 (VSS), U4.47 (VSS), U5.6 (VSS), U5.11 (A0), U5.12 (A1), U5.13 (A2), U6.1 (GND), X1.2 (GND_1), X1.4 (GND_2)
MISO: J4.8 (MISO), U4.16 (PA6), U5.10 (SO)
MOSI: J4.7 (MOSI), U4.17 (PA7), U5.9 (SI)
unnamed: R24.1, U5.14 (!RESET)
unnamed: J5.A5 (CC1), R60.1
unnamed: J5.B5 (CC2), R61.2
NRST: C17.1, J6.4, U4.7 (NRST)
OSC_IN: C6.1, U4.5 (OSC_IN), X1.1 (HOT_1)
OSC_OUT: C7.1, U4.6 (OSC_OUT), X1.3 (HOT_2)
SCLK: J4.6 (SCLK), U4.15 (PA5), U5.8 (SCK)
SW28: R50.1, SW28.1 (A1), U5.27 (GPB2)
SW29: R51.1, SW29.1 (A1), U5.1 (GPB4)
SW30: R52.1, SW30.2 (A2), U5.17 (GPA0)
SW31: R53.1, SW31.1 (A1), U5.2 (GPB5)
SW32: R54.1, SW32.2 (A2), U5.18 (GPA1)
SW33: R55.1, SW33.1 (A1), U5.3 (GPB6)
SW34: R56.1, SW34.2 (A2), U5.19 (GPA2)
SWCLK: J6.2, U4.37 (PA14)
SWDIO: J6.3, U4.34 (PA13)
USB_D+: J5.A6 (DP1), J5.B6 (DP2), U4.33 (PA12)
USB_D-: J5.A7 (DN1), J5.B7 (DN2), U4.32 (PA11)
VCAP: C18.1, U4.22 (VCAP1)

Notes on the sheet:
USB Connector
Power Supply
MCU
Debugger Port
Inter PCB Bus
I/O Extenders
Rotary Encoders
AUX Switch
Push Buttons
Pull up/down Resistors: 10KΩ x 35
SimHID G1000 - Right PCB

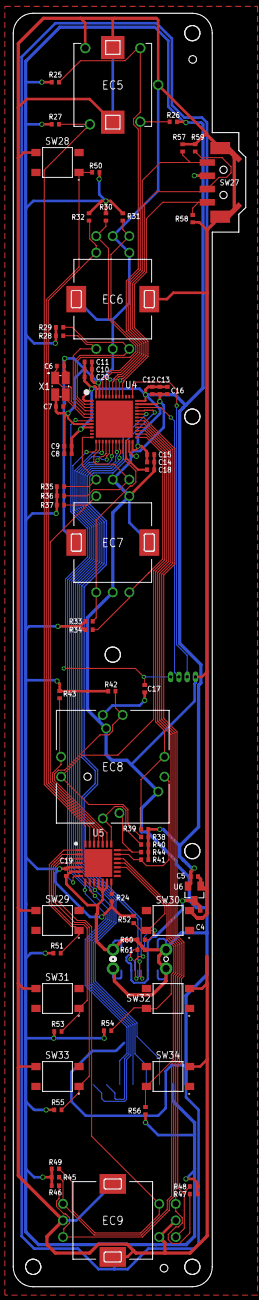
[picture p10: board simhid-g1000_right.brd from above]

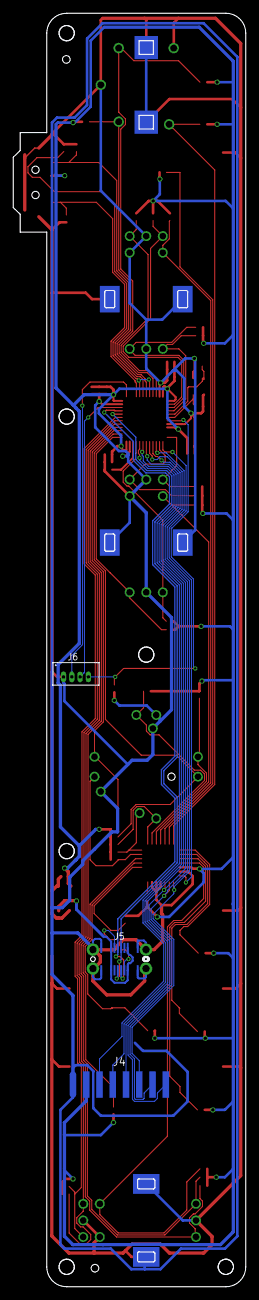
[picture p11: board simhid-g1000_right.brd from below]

Board: 2 copper layers, 35.0 x 192.0 mm, 75 parts (3 on the bottom side), 56 nets.

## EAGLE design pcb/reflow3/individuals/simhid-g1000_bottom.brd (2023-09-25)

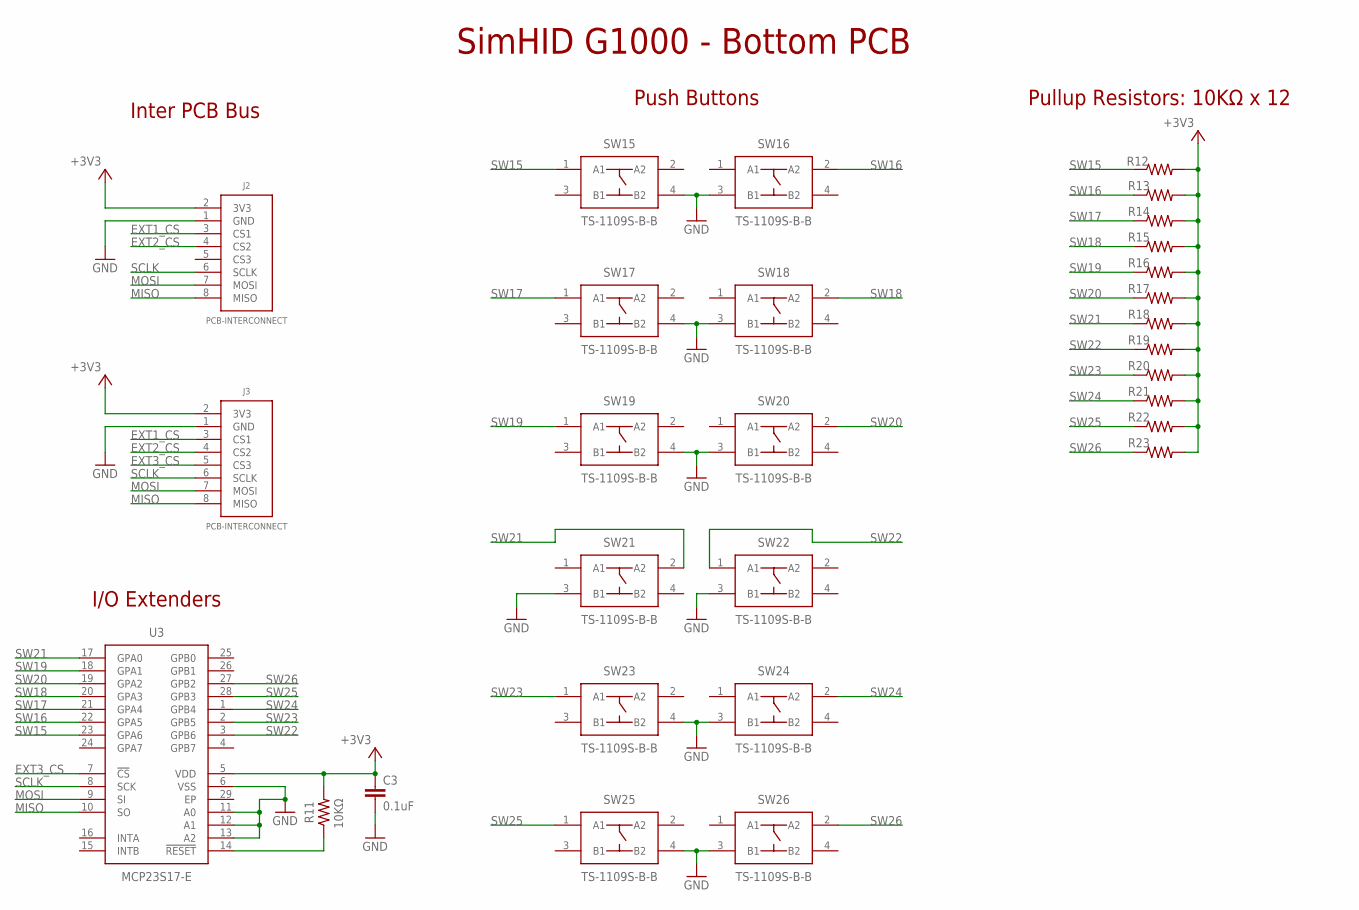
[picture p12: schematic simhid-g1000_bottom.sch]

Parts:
C3: 0.1uF; RCL_C0402_HS
J2, J3: PCB-INTERCONNECT
R11: 10KΩ; RCL_R0402_HS
R12, R13, R14, R15, R16, R17, R18, R19, R20, R21, R22, R23: RCL_R-US_R0402-HS; RCL_R0402_HS
SW15, SW16, SW17, SW18, SW19, SW20, SW21, SW22, SW23, SW24, SW25, SW26: TS-1109S-B-B
U3: MCP23S17-E; QFN65P600X600X100-29N

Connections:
+3V3: C3.1, J2.2 (3V3), J3.2 (3V3), R11.2, R12.2, R13.2, R14.2, R15.2, R16.2, R17.2, R18.2, R19.2, R20.2, R21.2, R22.2, R23.2, U3.5 (VDD)
EXT1_CS: J2.3 (CS1), J3.3 (CS1)
EXT2_CS: J2.4 (CS2), J3.4 (CS2)
EXT3_CS: J3.5 (CS3), U3.7 (!CS)
GND: C3.2, J2.1 (GND), J3.1 (GND), SW15.4 (B2), SW16.3 (B1), SW17.4 (B2), SW18.3 (B1), SW19.4 (B2), SW20.3 (B1), SW21.3 (B1), SW22.3 (B1), SW23.4 (B2), SW24.3 (B1), SW25.4 (B2), SW26.3 (B1), U3.6 (VSS), U3.11 (A0), U3.12 (A1), U3.13 (A2)
MISO: J2.8 (MISO), J3.8 (MISO), U3.10 (SO)
MOSI: J2.7 (MOSI), J3.7 (MOSI), U3.9 (SI)
RESET: R11.1, U3.14 (!RESET)
SCLK: J2.6 (SCLK), J3.6 (SCLK), U3.8 (SCK)
SW15: R12.1, SW15.1 (A1), U3.23 (GPA6)
SW16: R13.1, SW16.2 (A2), U3.22 (GPA5)
SW17: R14.1, SW17.1 (A1), U3.21 (GPA4)
SW18: R15.1, SW18.2 (A2), U3.20 (GPA3)
SW19: R16.1, SW19.1 (A1), U3.18 (GPA1)
SW20: R17.1, SW20.2 (A2), U3.19 (GPA2)
SW21: R18.1, SW21.2 (A2), U3.17 (GPA0)
SW22: R19.1, SW22.1 (A1), U3.3 (GPB6)
SW23: R20.1, SW23.1 (A1), U3.2 (GPB5)
SW24: R21.1, SW24.2 (A2), U3.1 (GPB4)
SW25: R22.1, SW25.1 (A1), U3.28 (GPB3)
SW26: R23.1, SW26.2 (A2), U3.27 (GPB2)

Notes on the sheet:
Inter PCB Bus
I/O Extenders
Push Buttons
Pullup Resistors: 10KΩ x 12
SimHID G1000 - Bottom PCB

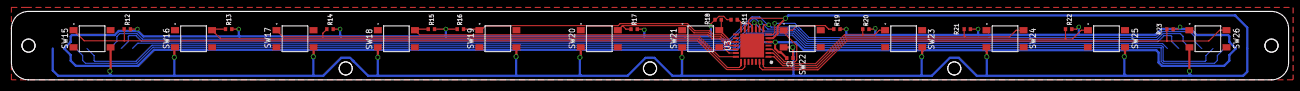
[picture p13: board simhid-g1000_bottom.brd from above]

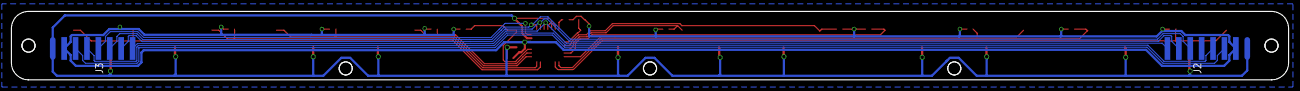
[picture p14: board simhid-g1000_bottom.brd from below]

Board: 2 copper layers, 224.0 x 12.0 mm, 29 parts (2 on the bottom side), 21 nets.

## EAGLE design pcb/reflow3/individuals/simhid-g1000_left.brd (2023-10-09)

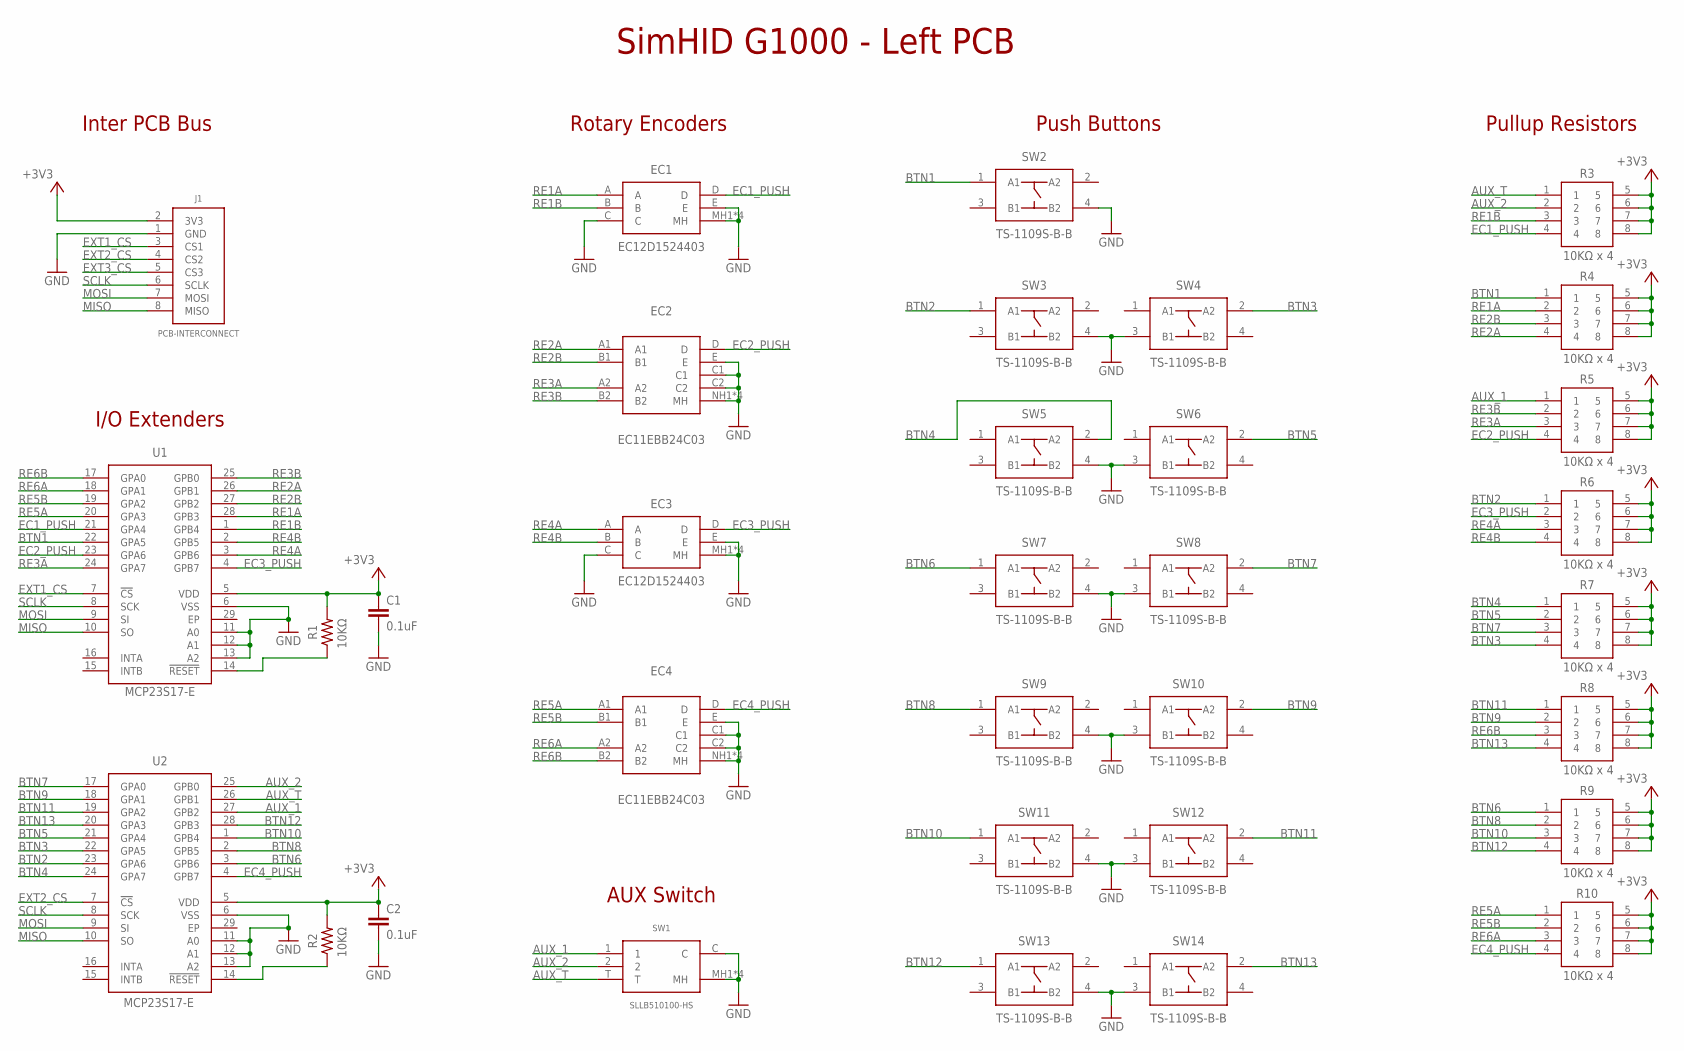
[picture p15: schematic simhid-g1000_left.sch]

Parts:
C1, C2: 0.1uF; RCL_C0402_HS
EC1, EC3: EC12D1524403
EC2, EC4: EC11EBB24C03
J1: PCB-INTERCONNECT
R1, R2: 10KΩ; RCL_R0402_HS
R3, R4, R5, R6, R7, R8, R9, R10: 10KΩ x 4; BCN164A_1
SW1: SLLB510100-HS
SW2, SW3, SW4, SW5, SW6, SW7, SW8, SW9, SW10, SW11, SW12, SW13, SW14: TS-1109S-B-B
U1, U2: MCP23S17-E; QFN65P600X600X100-29N

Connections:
+3V3: C1.1, C2.1, J1.2 (3V3), R1.2, R2.2, R3.5, R3.6, R3.7, R3.8, R4.5, R4.6, R4.7, R4.8, R5.5, R5.6, R5.7, R5.8, R6.5, R6.6, R6.7, R6.8, R7.5, R7.6, R7.7, R7.8, R8.5, R8.6, R8.7, R8.8, R9.5, R9.6, R9.7, R9.8, R10.5, R10.6, R10.7, R10.8, U1.5 (VDD), U2.5 (VDD)
AUX_1: R5.1, SW1.1, U2.27 (GPB2)
AUX_2: R3.2, SW1.2, U2.25 (GPB0)
AUX_T: R3.1, SW1.T, U2.26 (GPB1)
BTN1: R4.1, SW2.1 (A1), U1.22 (GPA5)
BTN2: R6.1, SW3.1 (A1), U2.23 (GPA6)
BTN3: R7.4, SW4.2 (A2), U2.22 (GPA5)
BTN4: R7.1, SW5.2 (A2), U2.24 (GPA7)
BTN5: R7.2, SW6.2 (A2), U2.21 (GPA4)
BTN6: R9.1, SW7.1 (A1), U2.3 (GPB6)
BTN7: R7.3, SW8.2 (A2), U2.17 (GPA0)
BTN8: R9.2, SW9.1 (A1), U2.2 (GPB5)
BTN9: R8.2, SW10.2 (A2), U2.18 (GPA1)
BTN10: R9.3, SW11.1 (A1), U2.1 (GPB4)
BTN11: R8.1, SW12.2 (A2), U2.19 (GPA2)
BTN12: R9.4, SW13.1 (A1), U2.28 (GPB3)
BTN13: R8.4, SW14.2 (A2), U2.20 (GPA3)
EC1_PUSH: EC1.D, R3.4, U1.21 (GPA4)
EC2_PUSH: EC2.D, R5.4, U1.23 (GPA6)
EC3_PUSH: EC3.D, R6.2, U1.4 (GPB7)
EC4_PUSH: EC4.D, R10.4, U2.4 (GPB7)
EXT1_CS: J1.3 (CS1), U1.7 (!CS)
EXT2_CS: J1.4 (CS2), U2.7 (!CS)
EXT3_CS: J1.5 (CS3)
GND: C1.2, C2.2, EC1.C, EC1.E, EC1.MH1 (MH), EC1.MH2 (MH), EC1.MH3 (MH), EC1.MH4 (MH), EC2.C1, EC2.C2, EC2.E, EC2.NH1 (MH), EC2.NH2 (MH), EC2.NH3 (MH), EC2.NH4 (MH), EC3.C, EC3.E, EC3.MH1 (MH), EC3.MH2 (MH), EC3.MH3 (MH), EC3.MH4 (MH), EC4.C1, EC4.C2, EC4.E, EC4.NH1 (MH), EC4.NH2 (MH), EC4.NH3 (MH), EC4.NH4 (MH), J1.1 (GND), SW1.C, SW1.MH1 (MH), SW1.MH2 (MH), SW1.MH3 (MH), SW1.MH4 (MH), SW2.4 (B2), SW3.4 (B2), SW4.3 (B1), SW5.4 (B2), SW6.3 (B1), SW7.4 (B2), SW8.3 (B1), SW9.4 (B2), SW10.3 (B1), SW11.4 (B2), SW12.3 (B1), SW13.4 (B2), SW14.3 (B1), U1.6 (VSS), U1.11 (A0), U1.12 (A1), U1.13 (A2), U2.6 (VSS), U2.11 (A0), U2.12 (A1), U2.13 (A2)
MISO: J1.8 (MISO), U1.10 (SO), U2.10 (SO)
MOSI: J1.7 (MOSI), U1.9 (SI), U2.9 (SI)
unnamed: R1.1, U1.14 (!RESET)
unnamed: R2.1, U2.14 (!RESET)
RE1A: EC1.A, R4.2, U1.28 (GPB3)
RE1B: EC1.B, R3.3, U1.1 (GPB4)
RE2A: EC2.A1, R4.4, U1.26 (GPB1)
RE2B: EC2.B1, R4.3, U1.27 (GPB2)
RE3A: EC2.A2, R5.3, U1.24 (GPA7)
RE3B: EC2.B2, R5.2, U1.25 (GPB0)
RE4A: EC3.A, R6.3, U1.3 (GPB6)
RE4B: EC3.B, R6.4, U1.2 (GPB5)
RE5A: EC4.A1, R10.1, U1.20 (GPA3)
RE5B: EC4.B1, R10.2, U1.19 (GPA2)
RE6A: EC4.A2, R10.3, U1.18 (GPA1)
RE6B: EC4.B2, R8.3, U1.17 (GPA0)
SCLK: J1.6 (SCLK), U1.8 (SCK), U2.8 (SCK)

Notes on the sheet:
Inter PCB Bus
I/O Extenders
Rotary Encoders
AUX Switch
Push Buttons
SimHID G1000 - Left PCB
Pullup Resistors

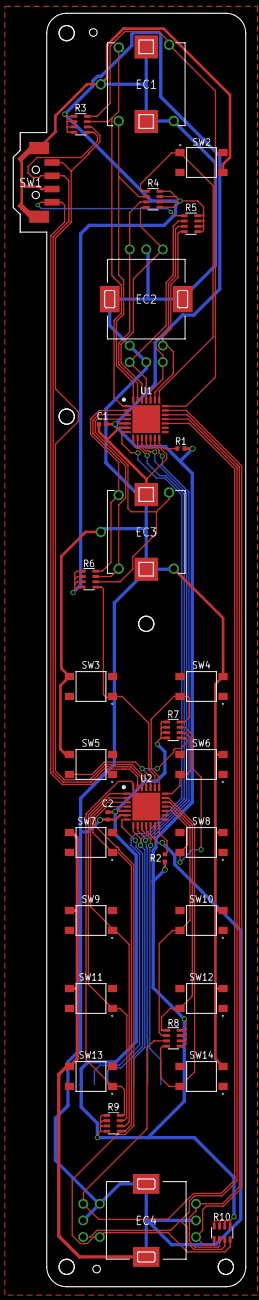
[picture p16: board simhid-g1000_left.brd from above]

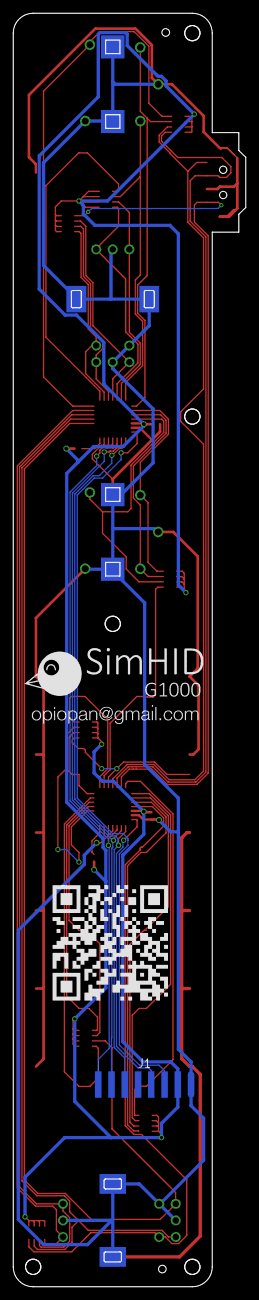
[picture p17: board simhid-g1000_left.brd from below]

Board: 2 copper layers, 35.0 x 192.0 mm, 35 parts (3 on the bottom side), 41 nets.

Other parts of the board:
U$1: SHIMHID-G1000-QRCODE
U$2: SIMHID-G1000-LOGO

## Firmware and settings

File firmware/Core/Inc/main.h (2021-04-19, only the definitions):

#define EC6YA_Pin GPIO_PIN_13
#define EC6YA_GPIO_Port GPIOC
#define EC6XB_Pin GPIO_PIN_14
#define EC6XB_GPIO_Port GPIOC
#define EC6XA_Pin GPIO_PIN_15
#define EC6XA_GPIO_Port GPIOC
#define EC7YA_Pin GPIO_PIN_2
#define EC7YA_GPIO_Port GPIOA
#define EXT4CS_Pin GPIO_PIN_3
#define EXT4CS_GPIO_Port GPIOA
#define EC7YB_Pin GPIO_PIN_4
#define EC7YB_GPIO_Port GPIOA
#define EXT3CS_Pin GPIO_PIN_0
#define EXT3CS_GPIO_Port GPIOB
#define EXT2CS_Pin GPIO_PIN_1
#define EXT2CS_GPIO_Port GPIOB
#define EXT1CS_Pin GPIO_PIN_2
#define EXT1CS_GPIO_Port GPIOB
#define EC7XA_Pin GPIO_PIN_10
#define EC7XA_GPIO_Port GPIOB
#define EC7XB_Pin GPIO_PIN_12
#define EC7XB_GPIO_Port GPIOB
#define EC8A_Pin GPIO_PIN_13
#define EC8A_GPIO_Port GPIOB
#define EC8B_Pin GPIO_PIN_14
#define EC8B_GPIO_Port GPIOB
#define EC9XA_Pin GPIO_PIN_15
#define EC9XA_GPIO_Port GPIOB
#define EC9XB_Pin GPIO_PIN_8
#define EC9XB_GPIO_Port GPIOA
#define EC9YA_Pin GPIO_PIN_9
#define EC9YA_GPIO_Port GPIOA
#define EC9YB_Pin GPIO_PIN_10
#define EC9YB_GPIO_Port GPIOA
#define AUX2D_Pin GPIO_PIN_4
#define AUX2D_GPIO_Port GPIOB
#define AUX2P_Pin GPIO_PIN_5
#define AUX2P_GPIO_Port GPIOB
#define AUX2U_Pin GPIO_PIN_6
#define AUX2U_GPIO_Port GPIOB
#define EC5B_Pin GPIO_PIN_7
#define EC5B_GPIO_Port GPIOB
#define EC5A_Pin GPIO_PIN_8
#define EC5A_GPIO_Port GPIOB
#define EC6YB_Pin GPIO_PIN_9
#define EC6YB_GPIO_Port GPIOB

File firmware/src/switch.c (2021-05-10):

/*
 * switch.c
 *  Author: Hiroshi Murayama <opiopan@gmail.com>
 */

#include <stdio.h>
#include <string.h>
#include "switch.h"
#include "olog.h"

/*========================================================
 Dirty ring buffer
========================================================*/
void vsbuf_init(VSWITCH_DIRTY_BUF *ctx, VSWITCH_CTX **buf, int bufsize)
{
    ctx->top = 0;
    ctx->bottom = 0;
    ctx->buf = buf;
    ctx->mask = bufsize - 1;
}

void vsbuf_push(VSWITCH_DIRTY_BUF *ctx, VSWITCH_CTX *data)
{
    if (data->isDirty){
        return;
    }
    if (ctx->bottom - ctx->top > ctx->mask){
        VSWITCH_CTX* sw = vsbuf_pop(ctx);
        sw->ops->commit(sw);
    }

    data->isDirty = TRUE;
    ctx->buf[ctx->bottom & ctx->mask] = data;
    ctx->bottom++;
}

VSWITCH_CTX *vsbuf_pop(VSWITCH_DIRTY_BUF *ctx)
{
    if (VSBUF_LENGTH(ctx) <= 0){
        return NULL;
    }
    VSWITCH_CTX* data = ctx->buf[ctx->top & ctx->mask];
    data->isDirty = FALSE;
    ctx->top++;
    return data;
}

/*========================================================
Simple switch
========================================================*/
static BOOL ss_update(VSWITCH_CTX *ctx, uint32_t data, int now)
{
    SimpleSwitchCtx *rctx = (SimpleSwitchCtx *)ctx;
    BOOL current = ((data & rctx->mask) != 0) ^ rctx->reversePolarity;
    BOOL rc = FALSE;
    if (rctx->indoubt){
        if (rctx->state == current){
            rctx->indoubt = FALSE;
        }else if (now - rctx->changeTime >= rctx->filterPeriod){
            rctx->indoubt = FALSE;
            rctx->state = current;
            rc = TRUE;
        }
    }else if (rctx->state != current){
        rctx->indoubt = TRUE;
        rctx->changeTime = now;
    }
    return rc;
}

static int32_t ss_getmask(VSWITCH_CTX* ctx)
{
    SimpleSwitchCtx *rctx = (SimpleSwitchCtx *)ctx;
    return rctx->mask;
}

static int32_t ss_getvalue(VSWITCH_CTX *ctx)
{
    SimpleSwitchCtx *rctx = (SimpleSwitchCtx *)ctx;
    return rctx->state;
}
static int32_t ss_getrawvalue(VSWITCH_CTX *ctx)
{
    SimpleSwitchCtx *rctx = (SimpleSwitchCtx *)ctx;
    return rctx->indoubt ? !rctx->state : rctx->state;
}

static void ss_commit(VSWITCH_CTX *ctx)
{
}

static int ss_printstate(VSWITCH_CTX *ctx, char *buf, int len)
{
    SimpleSwitchCtx *rctx = (SimpleSwitchCtx *)ctx;
    int rc = strlcpy(buf, rctx->common.name, len);
    buf[rc++] = ' ';
    buf[rc++] = rctx->state ? '1' : '0';
    buf[rc] = '\0';
    return rc;
}

static int ss_printdef(VSWITCH_CTX *ctx, char *buf, int len)
{
    return strlcpy(buf, "ABS 0 1", len);
}

    static int ss_printlog(VSWITCH_CTX *ctx, char *buf, int len)
{
    SimpleSwitchCtx *rctx = (SimpleSwitchCtx *)ctx;
    return snprintf(
        buf, len,
        "%s: %s", 
        rctx->description, rctx->state ? "ON" : "OFF");
}

const VSWITCH_OPS SimpleSwitchOps = {
    .update = ss_update,
    .getmask = ss_getmask,
    .getvalue = ss_getvalue,
    .getrawvalue = ss_getrawvalue,
    .commit = ss_commit,
    .printstate = ss_printstate,
    .printdef = ss_printdef,
    .printlog = ss_printlog,
};

/*========================================================
Rotary Encoder 
========================================================*/
typedef struct
{
    RE_STATE next;
    int delta;
} RESM;

static RESM RESM_UNKNOWN[] = {
    {RE_STOP1, 0},
    {RE_UNKNOWN, 0},
    {RE_UNKNOWN, 0},
    {RE_STOP2, 0}};

static RESM RESM_STOP1[] = {
    {RE_STOP1, 0},
    {RE_CW1, 0},
    {RE_CCW1, 0},
    {RE_STOP2, 0}};

static RESM RESM_CW1[] = {
    {RE_STOP1, 0},
    {RE_CW1, 0},
    {RE_UNKNOWN, 0},
    {RE_STOP2, 1}};

static RESM RESM_CCW1[] = {
    {RE_STOP1, 0},
    {RE_UNKNOWN, 0},
    {RE_CCW1, 0},
    {RE_STOP2, -1}};

static RESM RESM_STOP2[] = {
    {RE_STOP1, 0},
    {RE_CCW2, 0},
    {RE_CW2, 0},
    {RE_STOP2, 0}};

static RESM RESM_CW2[] = {
    {RE_STOP1, 1},
    {RE_UNKNOWN, 0},
    {RE_CW2, 0},
    {RE_STOP2, 0}};

static RESM RESM_CCW2[] = {
    {RE_STOP1, -1},
    {RE_CCW2, 0},
    {RE_UNKNOWN, 0},
    {RE_STOP2, 0}};

static RESM *resm[] = {
    RESM_UNKNOWN,
    RESM_STOP1,
    RESM_CW1,
    RESM_CCW1,
    RESM_STOP2,
    RESM_CW2,
    RESM_CCW2,
};

static BOOL re_update(VSWITCH_CTX *ctx, uint32_t data, int now)
{
    RotaryEncoderCtx* rctx = (RotaryEncoderCtx*)ctx;
    BOOL a = (data & rctx->amask) != 0;
    BOOL b = (data & rctx->bmask) != 0;
    int pat = a | b << 1;
    int delta = resm[rctx->state][pat].delta;
    rctx->state = resm[rctx->state][pat].next;
    rctx->counter += delta;
    return delta != 0;
}

static int32_t re_getmask(VSWITCH_CTX *ctx)
{
    RotaryEncoderCtx *rctx = (RotaryEncoderCtx *)ctx;
    return rctx->amask | rctx->bmask;
}

static int32_t re_getvalue(VSWITCH_CTX *ctx)
{
    RotaryEncoderCtx *rctx = (RotaryEncoderCtx *)ctx;
    return rctx->counter - rctx->last;
}

static int32_t re_getrawvalue(VSWITCH_CTX *ctx)
{
    RotaryEncoderCtx *rctx = (RotaryEncoderCtx *)ctx;
    return rctx->counter;
}

static void re_commit(VSWITCH_CTX *ctx)
{
    RotaryEncoderCtx *rctx = (RotaryEncoderCtx *)ctx;
    rctx->last = rctx->counter;
}

static int re_printstate(VSWITCH_CTX *ctx, char* buf, int len)
{
    RotaryEncoderCtx *rctx = (RotaryEncoderCtx *)ctx;
    return snprintf(buf, len, "%s %ld", 
                    rctx->common.name, 
                    (int32_t)(int8_t)((rctx->counter - rctx->last) & 0xff));
}

static int re_printdef(VSWITCH_CTX *ctx, char *buf, int len)
{
    return strlcpy(buf, "REL -128 127", len);
}
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

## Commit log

2021-04-29 basic switch scanning fuction has been implemented
2021-04-29 modify filter function for RKJXT1F42001 to handle raw data as negative logic
2021-04-30 fix a issue of filter for RKJXT1F42001
    [scanner.c]
2021-05-10 add a command to retrieve switch definitions
2021-09-16 add docmuments
    [simhid-g1000_bottom.brd, simhid-g1000_left.brd, simhid-g1000_right.brd]
2021-09-17 improve assemble procedure
2021-09-20 fix the issue that LPF for button input is not work
    [scanner.c]
2023-09-22 Added non-divisible PCB artwork with the goal of reducing manufacturing costs
    [BOM.csv, outline.dxf, simhid-g1000_bottom.brd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]
2023-09-25 Added vertical USB connector versions
    [BOM.csv, mousebites.dxf, outline.dxf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]
2023-10-09 revised pcb design for reflow
    [holes.dxf, outline.dxf, simhid-g1000_left.brd]
2024-12-31 added a PCB variant
    [BOM.csv, holes.dxf, mousebites.dxf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]
2025-01-11 improved the artwork for the new variant
    [simhid-g1000_right.brd]
2025-02-16 added a note to the README indicating that power supply via the USB port is required when programming the firmware via SWD
2025-06-26 added the parameter ‘B’ to the 'I' command to output BIT results
2025-07-12 modified the behavior so that initialization of MCP23S1* is retried once upon failure (issue #10)
    [switchgroup.c]
2025-09-06 Fix incorrect initialization parameters for MCP23S17 / MCP23S18 I misread the datasheet and misunderstood the effect of the IOCON register’s SEQOP bit. To enable Sequential Operation Mode, the SEQOP 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
    [mcp23s18.c]
2026-02-07 Modify the PCB design for USB Type-C
    [simhid-g1000_right.brd, simhid-g1000_right.sch]
2026-02-07 Minor chages of the PCB design for USB Type-C
    [simhid-g1000_right.brd, simhid-g1000_right.sch]
2026-02-09 Modified the README to describe PCB variant 3 and variant 4
2026-02-09 Improve the description for the PCB variants
2026-02-20 update the BOM for the variant 4 to correct the type-c connector footprint id
    [BOM.csv]

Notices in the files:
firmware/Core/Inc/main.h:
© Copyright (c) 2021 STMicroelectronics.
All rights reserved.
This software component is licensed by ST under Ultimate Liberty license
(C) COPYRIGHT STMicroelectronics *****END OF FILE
